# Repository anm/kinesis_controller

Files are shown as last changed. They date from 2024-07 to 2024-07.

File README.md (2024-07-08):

# River's Kinesis Advantage Blackpill based controller board

This is a replacement controller board for the Kinesis Advantage keyboard.
It is a development of the kinBP by https://github.com/DmNosachev.

Changes from that one:
- Added piezo sounder, allowing for key clicks / beepy tunes.
- Added connector for the original Kinesis cable. There is no need to buy extra USB cables and hack up the case!
- Removed some unneeded connectors, that were for a custom thumb board I'm not using.
- Aligned thumb connector holes properly so you can use the original cable.
- Completely rerouted.
- N.B.: The pins used for the matrix are different - you must use the correct QMK configuration, also provided on my github.

## Build Notes

- There are two options for orientation of the function key connectors. Test it works before soldering in.
- Obtain qmk keyboard files from https://github.com/anm/qmk_firmware/ river branch.
- Build QMK with `qmk flash -kb kinesis/river -km river`.
- Flash with dfu-util
- Flash: Enter bootloader by holding BOOT0 button while resetting / powering on the board, then
  `dfu-util -a 0 -d 0483:df11 -s 0x8000000:leave -D kinesis_river_blackpill411_river.bin`.
  After flashing, you can also enter the bootloader by holding both shift keys and B on the keyboard.

More info at the parent project: https://github.com/DmNosachev/kinbp

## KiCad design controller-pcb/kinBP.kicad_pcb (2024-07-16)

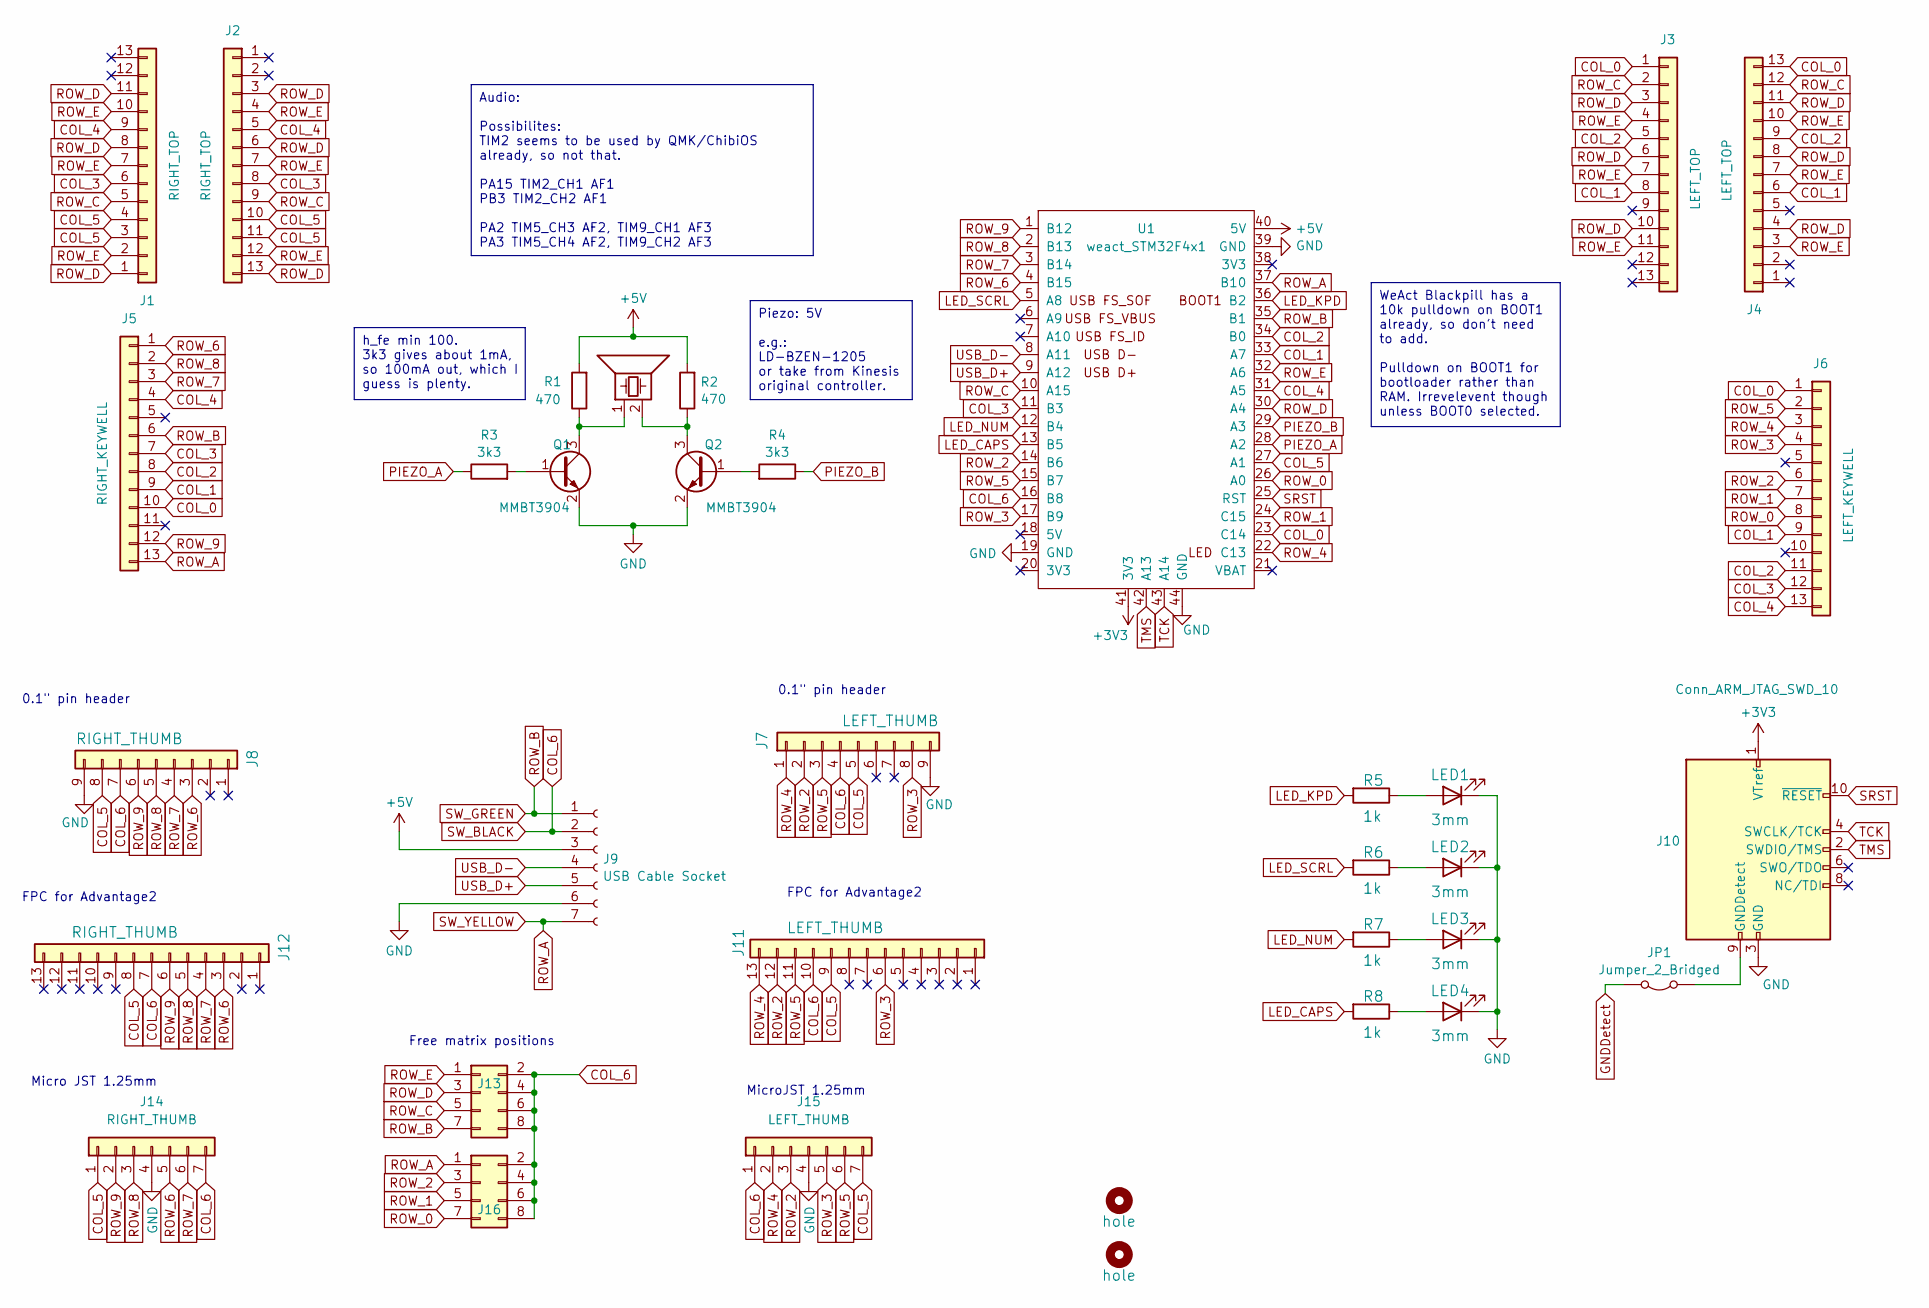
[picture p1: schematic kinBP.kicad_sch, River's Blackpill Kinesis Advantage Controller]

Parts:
H1: hole; MountingHole_4.3mm_M4_No_Copper
H2: hole; MountingHole_6mm
J1, J2: RIGHT_TOP; 39-53-2135
J3, J4: LEFT_TOP; 39-53-2135
J5: RIGHT_KEYWELL; 39-53-2135
J6: LEFT_KEYWELL; 39-53-2135
J7: LEFT_THUMB; PinHeader_1x09_P2.54mm_Vertical
J8: RIGHT_THUMB; PinHeader_1x09_P2.54mm_Vertical
J9: USB Cable Socket; JST_PH_B7B-PH-K_1x07_P2.00mm_Vertical
J10: Conn_ARM_JTAG_SWD_10; CONN_3220-10-0100-00_CNC; Digikey 1175-1627-ND
J11: LEFT_THUMB; 39-53-2135
J12: RIGHT_THUMB; 39-53-2135
J13, J16: Conn_02x04_Odd_Even; PinHeader_2x04_P2.54mm_Vertical
J14: RIGHT_THUMB; Molex_PicoBlade_53048-0710_1x07_P1.25mm_Horizontal
J15: LEFT_THUMB; Molex_PicoBlade_53048-0710_1x07_P1.25mm_Horizontal
JP1: Jumper_2_Bridged; SolderJumper-2_P1.3mm_Bridged2Bar_Pad1.0x1.5mm
LED1, LED2, LED3, LED4: 3mm; LED_D3.0mm_centered
LS1: LD-BZEN-1205LOUDITY; Piezos_12mm
Q1, Q2: MMBT3904; SOT-23
R1, R2: 470; R_Axial_DIN0207_L6.3mm_D2.5mm_P7.62mm_Horizontal
R3, R4: 3k3; R_Axial_DIN0207_L6.3mm_D2.5mm_P7.62mm_Horizontal
R5, R6, R7, R8: 1k; R_Axial_DIN0207_L6.3mm_D2.5mm_P7.62mm_Horizontal
U1: weact_STM32F4x1; STM32F4x1_MiniF4

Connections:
+3V3: J10.1 (VTref), U1.41 (3V3)
+5V: J9.3, R1.2, R2.2, U1.40 (5V)
COL_0: J3.1, J4.13, J5.10, J6.1, U1.23 (C14)
COL_1: J3.8, J4.6, J5.9, J6.9, U1.33 (A7)
COL_2: J3.5, J4.9, J5.8, J6.11, U1.34 (B0)
COL_3: J1.6, J2.8, J5.7, J6.12, U1.11 (B3)
COL_4: J1.9, J2.5, J5.4, J6.13, U1.31 (A5)
COL_5: J1.3, J1.4, J2.10, J2.11, J7.5, J8.8, J11.9, J12.8, J14.1, J15.7, U1.27 (A1)
COL_6: J7.4, J8.7, J9.2, J11.10, J12.7, J13.2, J13.4, J13.6, J13.8, J14.7, J15.1, J16.2, J16.4, J16.6, J16.8, U1.16 (B8)
GND: J7.9, J8.9, J9.6, J10.3 (GND), J10.5 (GND), J14.4, J15.4, LED1.1 (K), LED2.1 (K), LED3.1 (K), LED4.1 (K), Q1.2 (E), Q2.2 (E), U1.19 (GND), U1.39 (GND), U1.44 (GND)
GNDDetect: JP1.2 (B)
LED_CAPS: R8.2, U1.13 (B5)
LED_KPD: R5.2, U1.36 (B2)
LED_NUM: R7.2, U1.12 (B4)
LED_SCRL: R6.2, U1.5 (A8)
unnamed: J10.9 (GNDDetect), JP1.1 (A)
unnamed: LED1.2 (A), R5.1
unnamed: LED2.2 (A), R6.1
unnamed: LED3.2 (A), R7.1
unnamed: LED4.2 (A), R8.1
unnamed: Q1.1 (B), R3.2
unnamed: LS1.1, Q1.3 (C), R1.1
unnamed: Q2.1 (B), R4.2
unnamed: LS1.2, Q2.3 (C), R2.1
PIEZO_A: R3.1, U1.28 (A2)
PIEZO_B: R4.1, U1.29 (A3)
ROW_0: J6.8, J16.7, U1.26 (A0)
ROW_1: J6.7, J16.5, U1.24 (C15)
ROW_2: J6.6, J7.2, J11.12, J15.3, J16.3, U1.14 (B6)
ROW_3: J6.4, J7.8, J11.6, J15.5, U1.17 (B9)
ROW_4: J6.3, J7.1, J11.13, J15.2, U1.22 (C13)
ROW_5: J6.2, J7.3, J11.11, J15.6, U1.15 (B7)
ROW_6: J5.1, J8.3, J12.3, J14.5, U1.4 (B15)
ROW_7: J5.3, J8.4, J12.4, J14.6, U1.3 (B14)
ROW_8: J5.2, J8.5, J12.5, J14.3, U1.2 (B13)
ROW_9: J5.12, J8.6, J12.6, J14.2, U1.1 (B12)
ROW_A: J5.13, J9.7, J16.1, U1.37 (B10)
ROW_B: J5.6, J9.1, J13.7, U1.35 (B1)
ROW_C: J1.5, J2.9, J3.2, J4.12, J13.5, U1.10 (A15)
ROW_D: J1.1, J1.8, J1.11, J2.3, J2.6, J2.13, J3.3, J3.6, J3.10, J4.4, J4.8, J4.11, J13.3, U1.30 (A4)
ROW_E: J1.2, J1.7, J1.10, J2.4, J2.7, J2.12, J3.4, J3.7, J3.11, J4.3, J4.7, J4.10, J13.1, U1.32 (A6)
SRST: J10.10 (~RESET), U1.25 (RST)
TCK: J10.4 (SWCLK/TCK), U1.43 (A14)
TMS: J10.2 (SWDIO/TMS), U1.42 (A13)
USB_D+: J9.5, U1.9 (A12)
USB_D-: J9.4, U1.8 (A11)

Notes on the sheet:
Piezo: 5V e.g.: LD-BZEN-1205 or take from Kinesis original controller.
h_fe min 100. 3k3 gives about 1mA, so 100mA out, which I guess is plenty.
WeAct Blackpill has a 10k pulldown on BOOT1 already, so don't need to add. Pulldown on BOOT1 for bootloader rather than RAM. Irrevelevent though unless BOOT0 selected.
Audio: Possibilites: TIM2 seems to be used by QMK/ChibiOS already, so not that. PA15 TIM2_CH1 AF1 PB3 TIM2_CH2 AF1 PA2 TIM5_CH3 AF2, TIM9_CH1 AF3 PA3 TIM5_CH4 AF2, TIM9_CH2 AF3
FPC for Advantage2
0.1" pin header
MicroJST 1.25mm
Micro JST 1.25mm
Free matrix positions

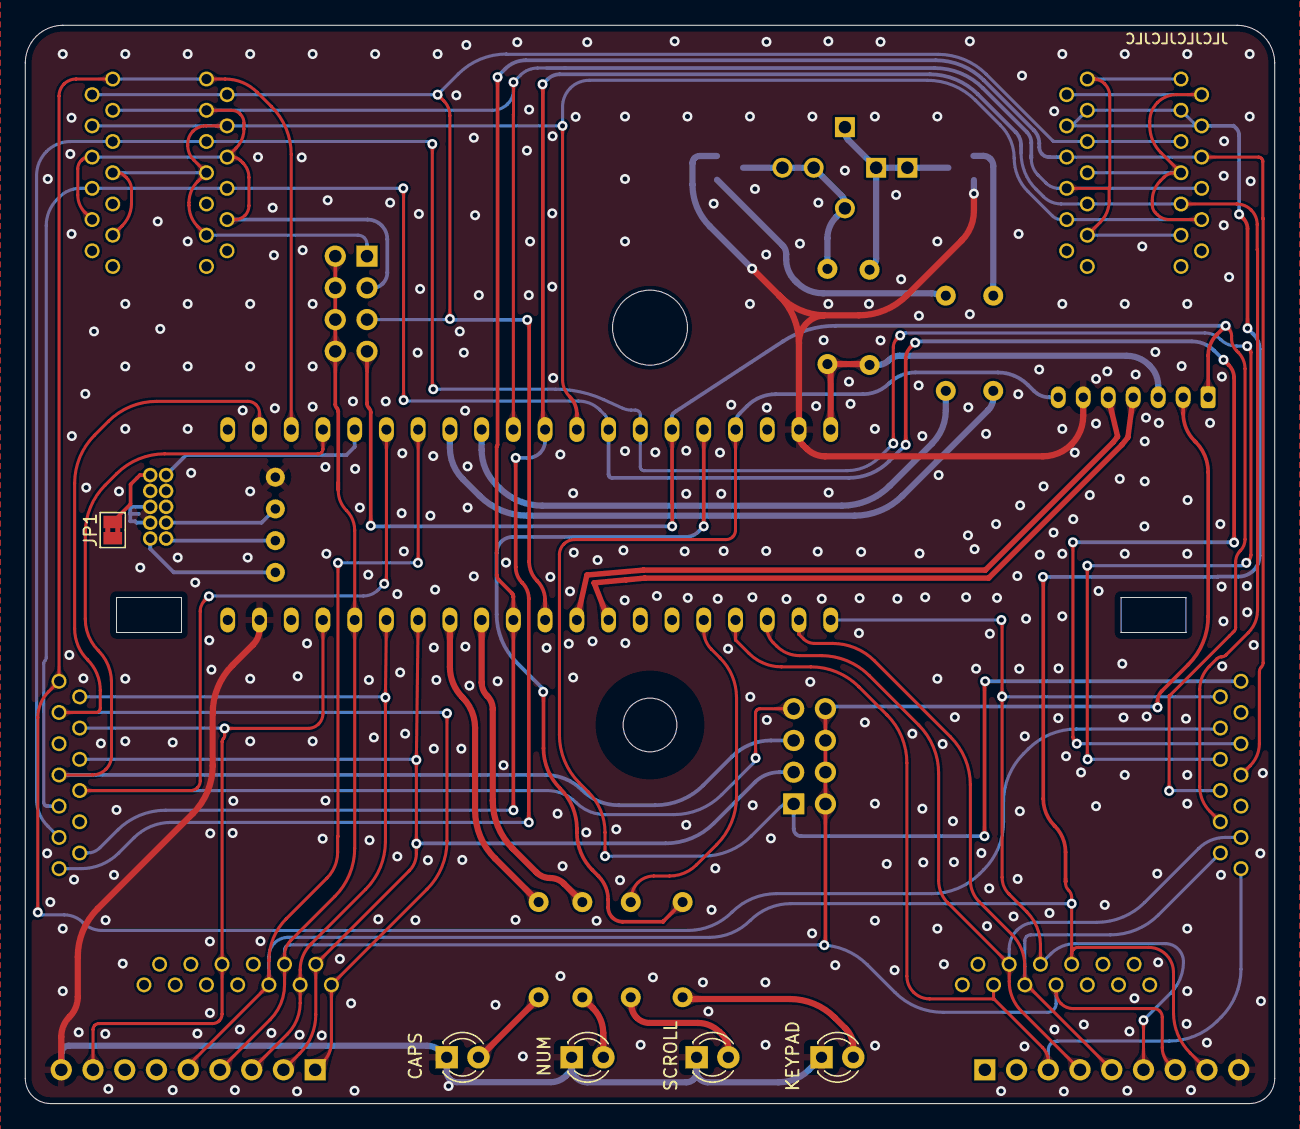
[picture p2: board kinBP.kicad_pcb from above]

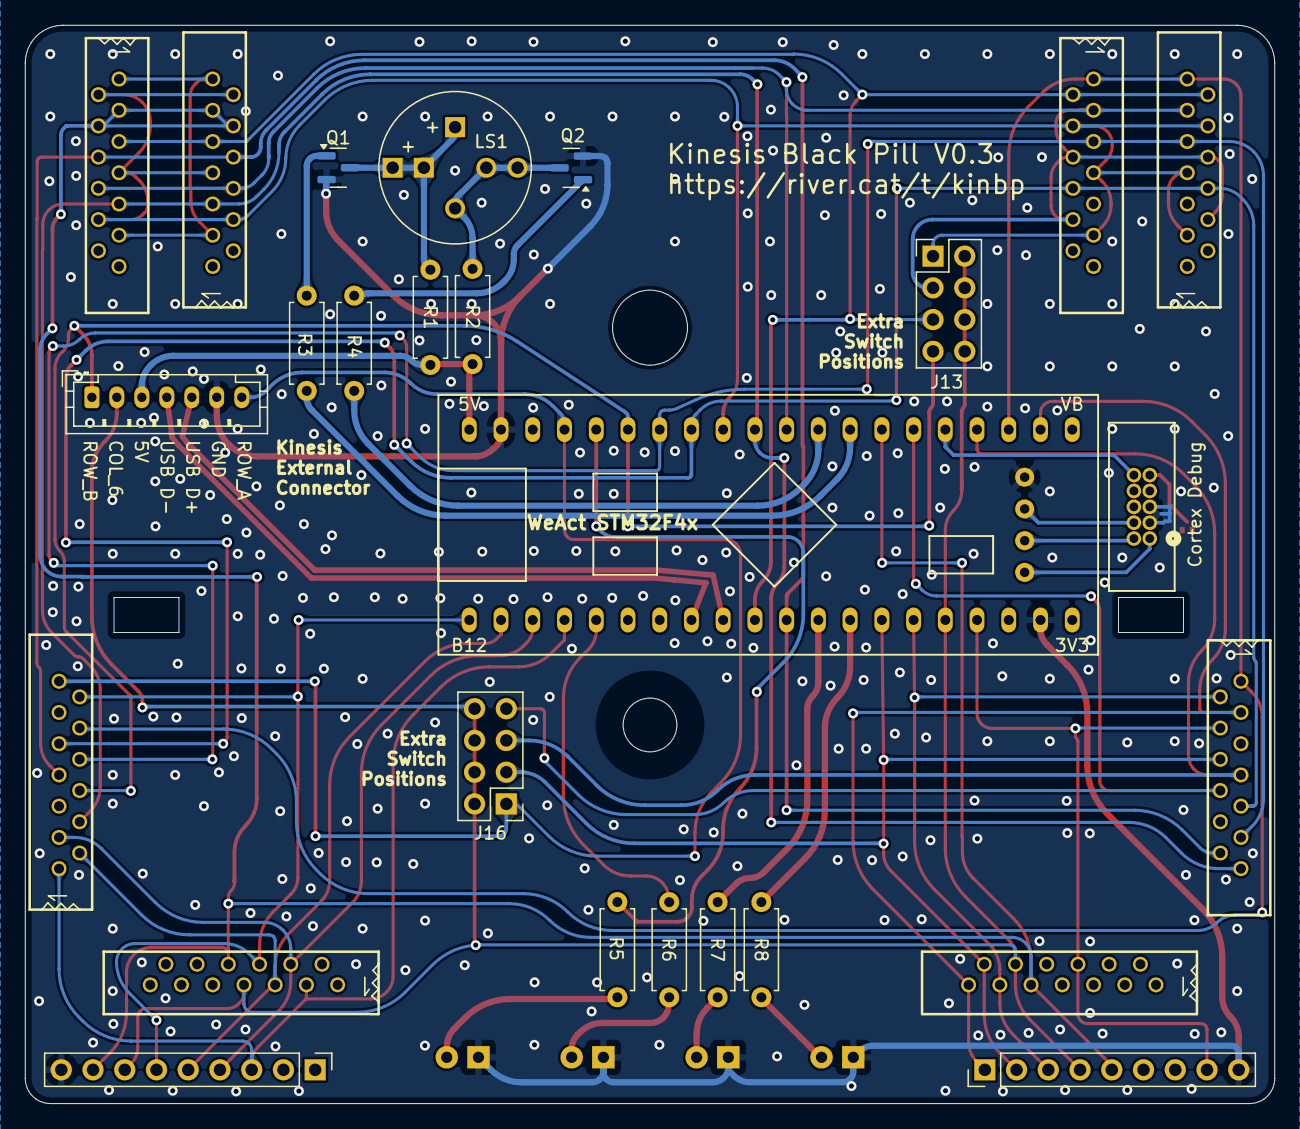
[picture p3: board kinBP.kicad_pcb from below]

Board: 2 copper layers, 100.0 x 86.3 mm, 33 parts (26 on the bottom side), 45 nets.

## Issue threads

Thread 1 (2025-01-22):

Could you add diode pads for the extra buttons?

LeoMegaAir, 2025-01-22:
Dear River, not really your project issue and I hate to be a pain in the butt but would you be able to add pads for the 1N4148 SOD-123 diodes to be used with the extra buttons' header? I know they have to be there but I have no idea how to add them to the PCB. I always added a radial lead diode to one of the wires going to the buttons but that looked so lame... a chance to have directly them on PCB would make life so much easier.

If you do, please let me know the required orientation (which way the cathode should be looking on the pad) or maybe even could put the orientation instructions on the mask?

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

anm, 2025-01-22:
I will probably not do this because I don't need it and have other projects to do, but it is an opportunity for you to learn KiCad. Phil's Lab on youtube has very good tutorials.

anm, 2025-01-22:
I will probably not do this because I don't need it and have other projects to do, but it is an opportunity for you to learn KiCad. Phil's Lab on youtube has very good tutorials.

anm, 2025-01-22:
I will probably not do this because I don't need it and have other projects to do, but it is an opportunity for you to learn KiCad. Phil's Lab on youtube has very good tutorials.

Closed 2025-01-22.

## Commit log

2024-03-06 River's modified version. Added piezo sounder. Rerouted. Split extra switch header.
    [kinBP.kicad_pcb, kinBP.kicad_sch]
2024-03-14 V0.1 as manufactured
    [kinBP.kicad_pcb]
2024-05-24 Added connector for original external USB / footpedal cable. Fixed LED positions. Prob other stuff I forgot.
    [kinBP.kicad_pcb, kinBP.kicad_sch]
2024-07-08 V0.2 as made, except then shifted screw hole down 0.2mm.
    [kinBP.kicad_pcb, kinBP.kicad_sch]
2024-07-08 Bumped version to V0.3. Added some notes, metadata.
    [kinBP.kicad_pcb, kinBP.kicad_sch]
2024-07-08 Removed gerbers and thumb pcbs.
    [kinbp-thumb-pcb.kicad_pcb, kinbp-thumb-pcb.kicad_sch]
2024-07-16 Added 10pin ARM Cortex debug header.
    [kinBP.kicad_pcb, kinBP.kicad_sch]
